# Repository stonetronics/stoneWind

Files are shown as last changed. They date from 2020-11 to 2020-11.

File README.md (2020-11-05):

# stoneWind

anemometer firmware for arduino uno based anemometer

This firmware and hardware enables an Arduino Uno to read the anemometer sensor found on https://www.thingiverse.com/thing:4216504
The Arduino shield (/hw) is drawn in Eagle 9.2.2, the Gerbers were generated for JLCPCB manufacturing
The Firmware (/src) is programmed in platformio

Features:
- 7 segment display
- sd card for logging and storage of lookup table
- ptc temperature sensor
- frequency counter
- schmitt trigger and signal conditioning/supply of the anemometer

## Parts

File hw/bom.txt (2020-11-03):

Stückliste exportiert aus /home/stone/GIT/stoneWind/hw/arduinoShield.sch am 18.09.20 22:02

Qty Value            Device                     Package          Parts                                           Description                                                                              CREATED_BY    DIGIKEY_PART_NUMBER MANUFACTURER     MF MPN      OC_FARNELL OC_NEWARK PACKAGE        PROD_ID     SPICEMODEL SPICEPREFIX SPICEPREFIXL VALUE         
1                    10-XX                      B3F-10XX         S1                                              OMRON SWITCH                                                                                                                                   B3F-1000 176432     36M3542                                                                                
3                    PINHD-1X1                  1X01             JP3, JP4, JP5                                   PIN HEADER                                                                                                                                                                                                                                                
1                    PINHD-1X2                  1X02             JP6                                             PIN HEADER                                                                                                                                                                                                                                                
2                    PINHD-1X4                  1X04             JP1, JP2                                        PIN HEADER                                                                                                                                                                                                                                                
3   100k             R-EU_R0805                 R0805            R7, R8, R14                                     RESISTOR, European symbol                                                                                                                                                                                          R                                      
10  100n             C-EUC0805                  C0805            C1, C2, C3, C7, C8, C9, C11, C12, C16, C18      CAPACITOR, European symbol                                                                                                                                                                                         C                                      
5   10k              R-EU_R0805                 R0805            R3, R4, R9, R13, R16                            RESISTOR, European symbol                                                                                                                                                                                          R                                      
6   150u             CPOL-EUD/7343-31R          D/7343-31R       C6, C10, C13, C14, C15, C17                     POLARIZED CAPACITOR, European symbol                                                                                                                                                                               C                                      
10  180R             R-EU_R0805                 R0805            R1, R15, R19, R20, R21, R22, R23, R24, R25, R26 RESISTOR, European symbol                                                                                                                                                                                          R                                      
1   1k5/1k8          R-EU_R0805                 R0805            R2                                              RESISTOR, European symbol                                                                                                                                                                                          R                                      
2   220k             R-EU_R0805                 R0805            R5, R6                                          RESISTOR, European symbol                                                                                                                                                                                          R                                      
1   2V4              DIODE-ZENER-BZT52C3V6S     SOD-323          D1                                              Zener Diode                                                                                                                                                                                 DIO-08199                                       3.6V          
1   330R             R-EU_R0805                 R0805            R12                                             RESISTOR, European symbol                                                                                                                                                                                          R                                      
2   4.3A/20V/54mΩ    MOSFET_PCH-IRLML2244       SOT23-3          Q3, Q4                                          P-channel MOSFETs                                                                                                                                                                           TRANS-11153                                     4.3A/20V/54mΩ 
2   500k             R-TRIMM64Y                 RTRIM64Y         R10, R11                                        Trimm resistor                                                                                                                                                                                          X                      POT                        
1   ARDUINO_UNO_R3   ARDUINO_UNO_R3_HOLES_NOISP ARDUINO_R3_NOISP B2                                                                                                                                                                                                                                                                                                        
1   BC847            BC847-NPN-SOT23-BEC        SOT23-BEC        T2                                              NPN Transistror                                                                                                                                                                                                                                           
1   BSS138           MOSFET-NCH-BSS138          SOT23-3          Q1                                              N-channel MOSFETs                                                                                                                                                                           TRANS-00830                                     220mA/50V/3.5Ω
1   IRLML2244        MOSFET_PCH-IRLML2244       SOT23-3          Q2                                              P-channel MOSFETs                                                                                                                                                                           TRANS-11153                                     4.3A/20V/54mΩ 
1   LM358D           LM358D                     SO08             IC1                                             OP AMP also LM158; LM258; LM2904                                                                                                                                                                                                                          
4   PESD5V0X1UB      PESD5V0X1UB                SOD523           D2, D3, D4, D5                                  Ultra low capacitance unidirectional ElectroStatic Discharge (ESD) protection diode in a                                                                                                                                                                  
1   PHOTOINTERRUPTER MKDSN1,5/3-5,08            MKDSN1,5/3-5,08  X2                                              MKDSN 1,5/ 3-5,08 Printklemme                                                                                                                                                                                                                             
1   PT100            PCB2_TERMINAL-BLOCK        2_2.54MM         X1                                              2 way PCB terminal block 2.54mm                                                                                                                                                                                                                           
1   REDSEVENSEGMENT  REDSEVENSEGMENT            REDSEVENSEGMENT  SSEG1                                           red 3 digit seven segment from neuhold electronic                                                                                                                                                                                                         
1   SDCARD_MODULE    SDCARD_MODULE              SD_MODULE        SD1                                             sd card module                                                                                                                                                                                                                                            
1   SS12             SS12                       SMA              D6                                              DIODE SCHOTTKY 20V 1A SMA                                                                PCBLayout.com SS12FSCT-ND         ON Semiconductor    SS12                          SMA (DO-214AC)                                                               
1   SUPPLY           MKDSN1,5/2-5,08            MKDSN1,5/2-5,08  X3                                              MKDSN 1,5/ 2-5,08 Printklemme

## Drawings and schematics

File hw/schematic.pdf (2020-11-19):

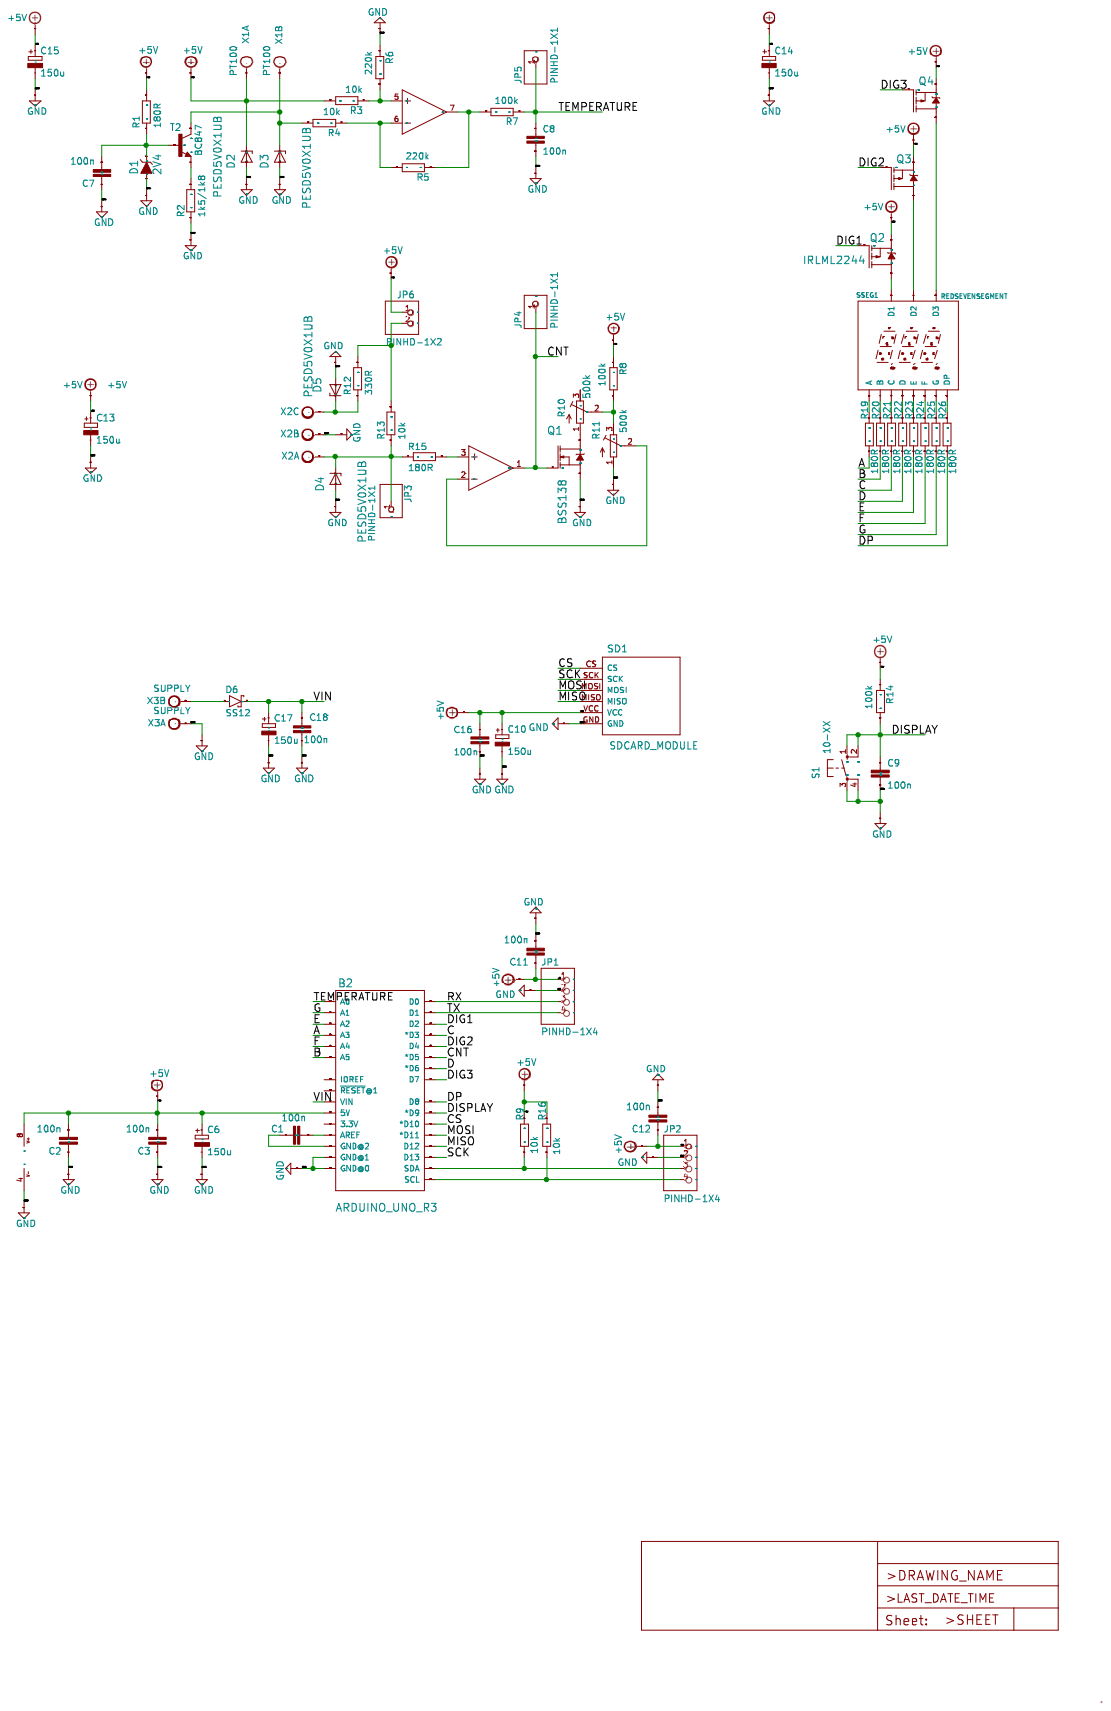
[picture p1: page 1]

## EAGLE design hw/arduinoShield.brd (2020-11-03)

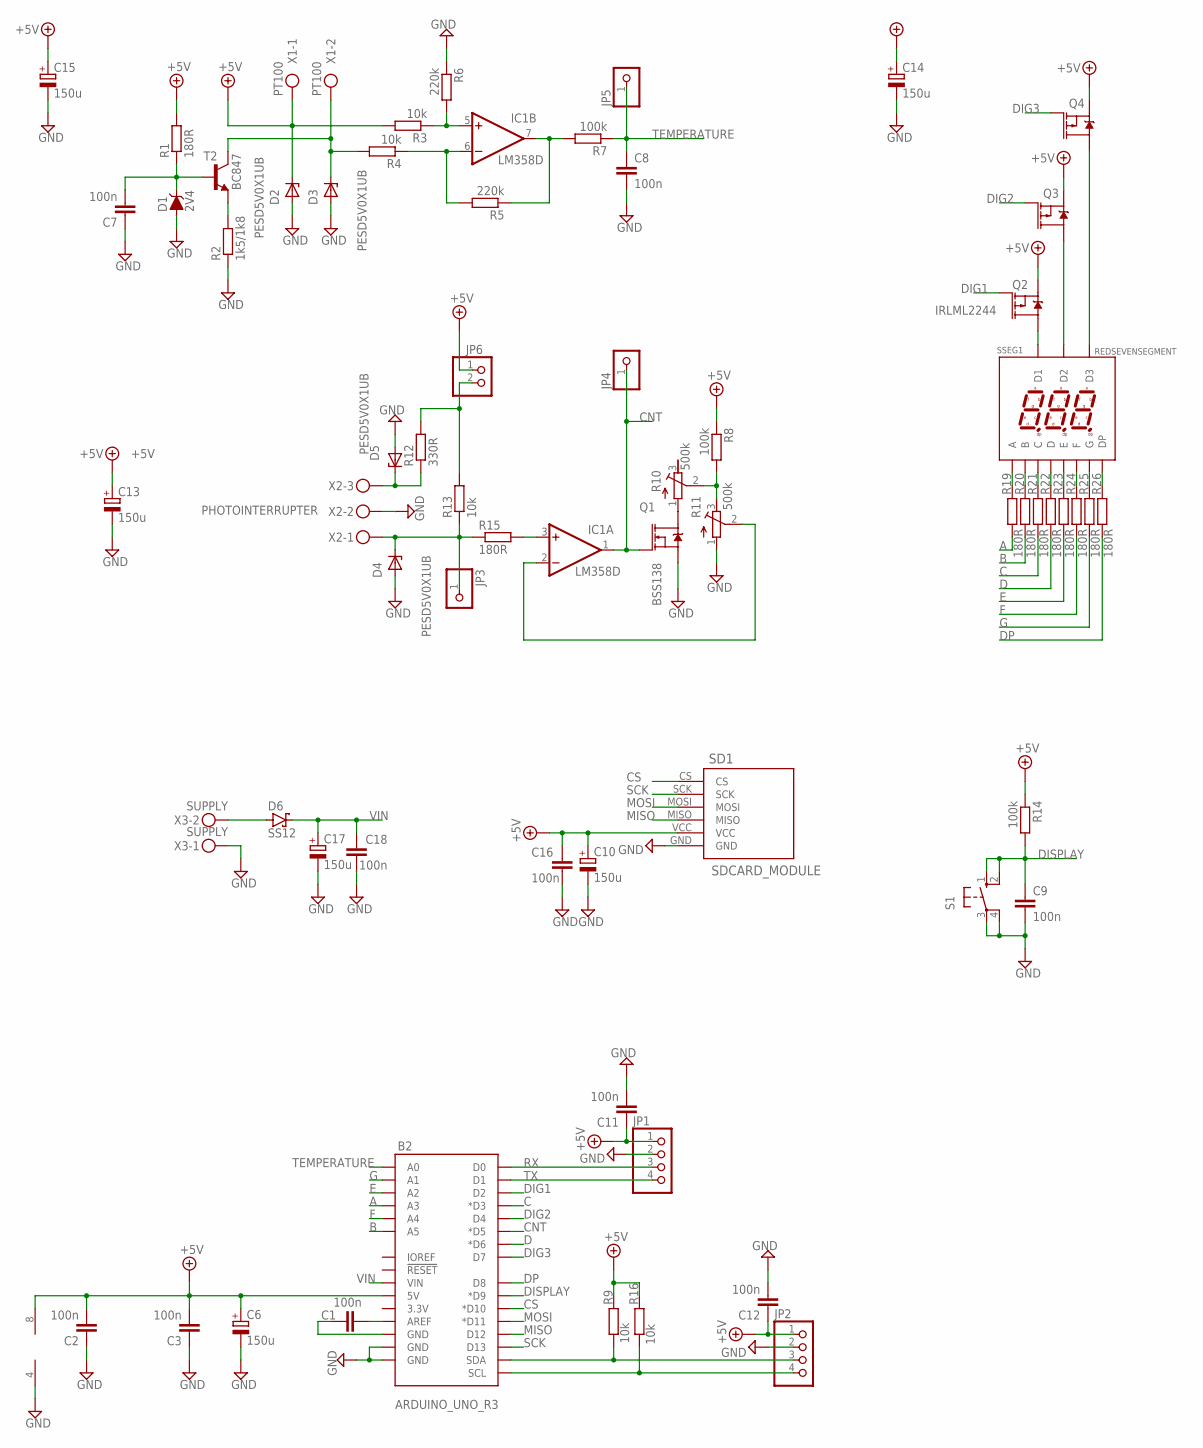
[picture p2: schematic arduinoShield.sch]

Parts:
B2: ARDUINO_UNO_R3; ARDUINO_R3_NOISP
C1, C2, C3, C7, C8, C9, C11, C12, C16, C18: 100n; C0805
C6, C10, C13, C14, C15, C17: 150u; D/7343-31R
D1: 2V4; SOD-323
D2, D3, D4, D5: PESD5V0X1UB; SOD523
D6: SS12; SMA
IC1: LM358D; SO08
JP1, JP2: PINHD-1X4; 1X04
JP3, JP4, JP5: PINHD-1X1; 1X01
JP6: PINHD-1X2; 1X02
Q1: BSS138; SOT23-3
Q2: IRLML2244; SOT23-3
Q3, Q4: 4.3A/20V/54mΩ; SOT23-3
R1, R15, R19, R20, R21, R22, R23, R24, R25, R26: 180R; R0805
R2: 1k5/1k8; R0805
R3, R4, R9, R13, R16: 10k; R0805
R5, R6: 220k; R0805
R7, R8, R14: 100k; R0805
R10, R11: 500k; RTRIM64Y
R12: 330R; R0805
S1: 10-XX; B3F-10XX
SD1: SDCARD_MODULE; SD_MODULE
SSEG1: REDSEVENSEGMENT
T2: BC847; SOT23-BEC
X1: PT100; 2_2.54MM
X2: PHOTOINTERRUPTER; MKDSN1,5/3-5,08
X3: SUPPLY; MKDSN1,5/2-5,08

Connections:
+5V: B2.5V, C2.2, C3.2, C6.+, C10.+, C11.1, C12.1, C13.+, C14.+, C15.+, C16.1, D2.1 (K), IC1.8 (V+), JP1.1, JP2.1, JP6.1, Q2.2 (S), Q3.2 (S), Q4.2 (S), R1.2, R3.2, R8.1, R9.2, R14.1, R16.2, SD1.VCC, X1.1
A: B2.A3, R19.1
B: B2.A5, R20.1
C: B2.D3 (*D3), R21.1
CNT: B2.D5 (*D5), IC1.1 (OUT), JP4.1, Q1.1 (G)
CS: B2.D10 (*D10), SD1.CS
D: B2.D6 (*D6), R22.1
DIG1: B2.D2, Q2.1 (G)
DIG2: B2.D4, Q3.1 (G)
DIG3: B2.D7, Q4.1 (G)
DISPLAY: B2.D9 (*D9), C9.1, R14.2, S1.1 (S), S1.2 (S1)
DP: B2.D8, R26.1
E: B2.A2, R23.1
F: B2.A4, R24.1
G: B2.A1, R25.1
GND: B2.GND@1 (GND), B2.GND@2 (GND), C2.1, C3.1, C6.-, C7.1, C8.2, C9.2, C10.-, C11.2, C12.2, C13.-, C14.-, C15.-, C16.2, C17.-, C18.1, D1.A, D2.2 (A), D3.2 (A), D4.2 (A), D5.2 (A), IC1.4 (V-), JP1.2, JP2.2, Q1.2 (S), R2.1, R6.1, R11.1 (A), S1.3, S1.4 (P1), SD1.GND, X2.2, X3.1
MISO: B2.D12, SD1.MISO
MOSI: B2.D11 (*D11), SD1.MOSI
unnamed: B2.AREF, C1.2
unnamed: C7.2, D1.C, R1.1, T2.B
unnamed: R2.2, T2.E
unnamed: D3.1 (K), R4.2, T2.C, X1.2
unnamed: IC1.5 (+IN), R3.1, R6.2
unnamed: IC1.6 (-IN), R4.1, R5.2
unnamed: IC1.7 (OUT), R5.1, R7.2
unnamed: D5.1 (K), R12.1, X2.3
unnamed: B2.SDA, JP2.3, R9.1
unnamed: Q1.3 (D), R10.1 (A)
unnamed: R8.2, R10.2 (S), R11.3 (E)
unnamed: IC1.2 (-IN), R11.2 (S)
unnamed: D4.1 (K), JP3.1, R13.1, R15.1, X2.1
unnamed: B2.SCL, JP2.4, R16.1
unnamed: JP6.2, R12.2, R13.2
unnamed: B2.GND@3 (GND), C1.1
unnamed: Q2.3 (D), SSEG1.2 (D1)
unnamed: Q3.3 (D), SSEG1.4 (D2)
unnamed: Q4.3 (D), SSEG1.5 (D3)
unnamed: D6.A, X3.2
unnamed: R19.2, SSEG1.9 (A)
unnamed: R20.2, SSEG1.7 (B)
unnamed: R21.2, SSEG1.1 (C)
unnamed: R22.2, SSEG1.3 (D)
unnamed: R23.2, SSEG1.10 (E)
unnamed: R24.2, SSEG1.8 (F)
unnamed: R25.2, SSEG1.11 (G)
unnamed: R26.2, SSEG1.6 (DP)
unnamed: IC1.3 (+IN), R15.2
RX: B2.D0, JP1.3
SCK: B2.D13, SD1.SCK
TEMPERATURE: B2.A0, C8.1, JP5.1, R7.1
TX: B2.D1, JP1.4
VIN: B2.VIN, C17.+, C18.2, D6.C

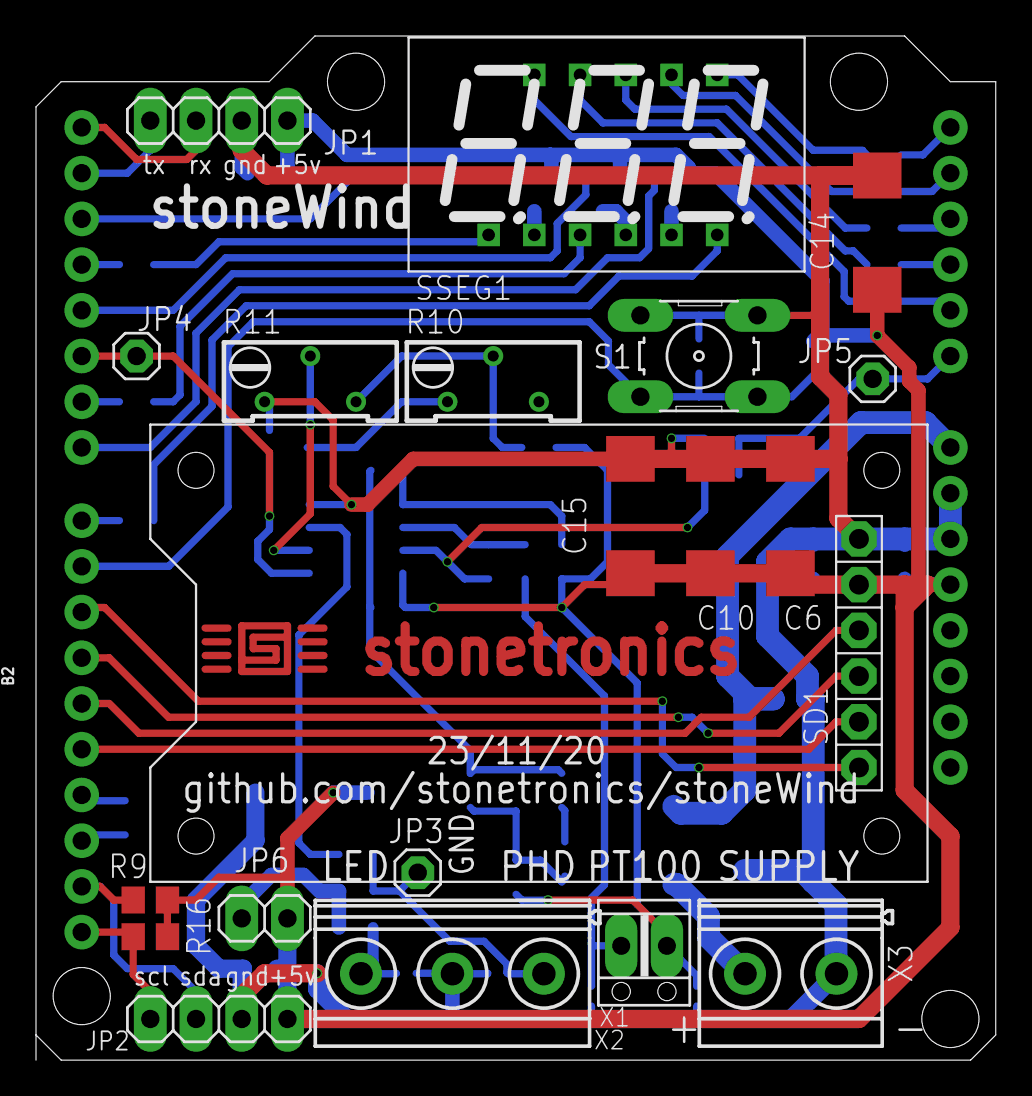
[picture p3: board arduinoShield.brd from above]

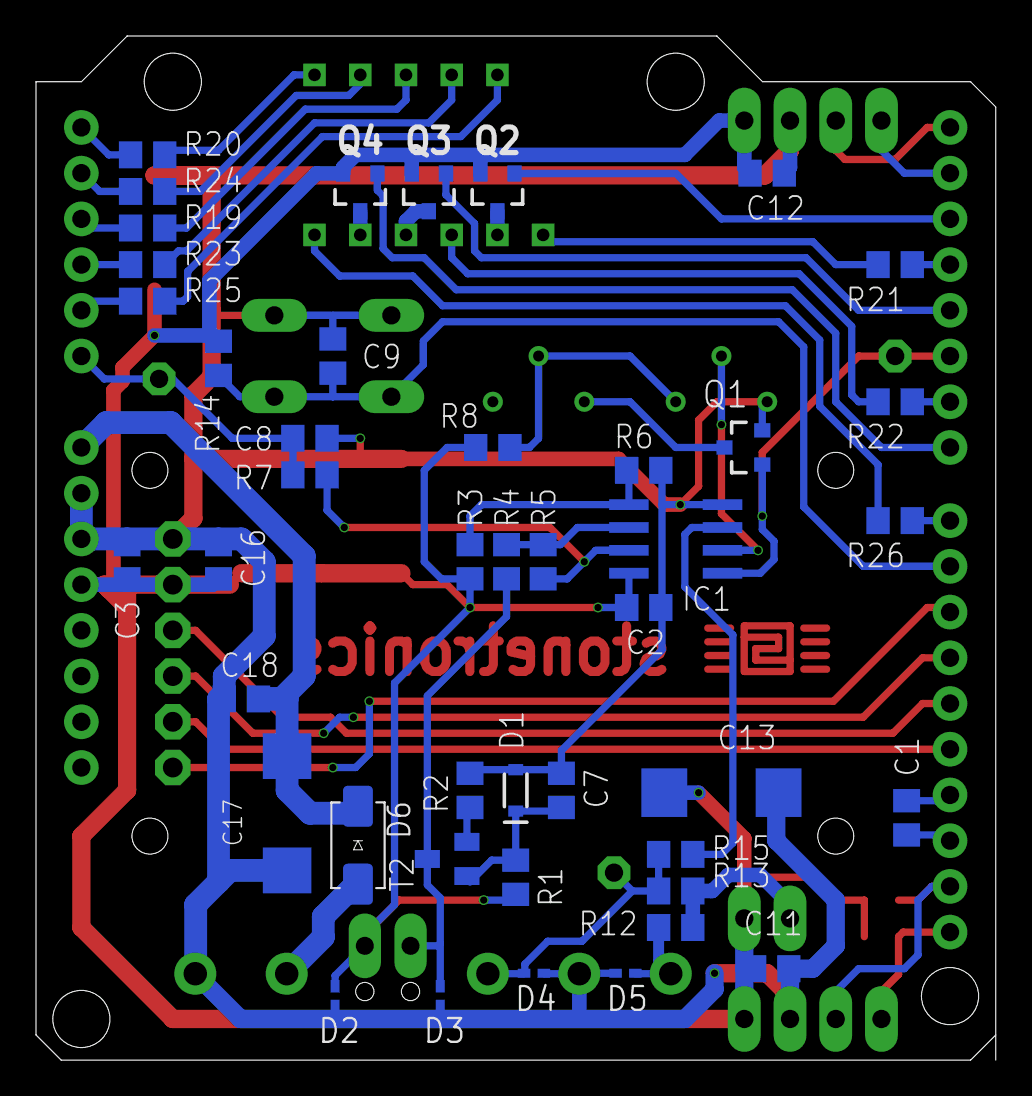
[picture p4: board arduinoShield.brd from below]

Board: 2 copper layers, 53.3 x 56.9 mm, 65 parts (44 on the bottom side), 52 nets.

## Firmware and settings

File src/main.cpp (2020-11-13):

#include <Arduino.h>
#include <SPI.h>
#include <SD.h>

#include "pindef.h"
#include "sevenSegment.h"
#include "freqCount.h"
#include "lookupTable.h"

LookupTable windFreqLUT;
LookupTable tempAdcLUT;

void setup() {
  Serial.begin(9600); //init serial
  Serial.println("stoneWind Anemomenter");

  //sd card init

  Serial.println("initializing SD card");
  if (!SD.begin(PIN_CS)) {
    Serial.println("initialization failed!");
    Serial.println("please insert sd card an reset");
    while (1);
  }
  Serial.println("initialization done.");

  //load lookup tables

  Serial.println("loading wind/frequency lookup table from /LUT/windFreq.csv");
  windFreqLUT.begin(12);
  if (windFreqLUT.loadFromFile("LUT/windFreq.csv") )
  {
    Serial.println("loading successful!");
    Serial.println("lookup table values:");
    windFreqLUT.printTable();
  } else {
    Serial.println("couldn't load wind/freq LUT!");
    while(1);
  }

  Serial.println("loading temperature/ADC lookup table from /LUT/tempAdc.csv");
  tempAdcLUT.begin(12);
  if (tempAdcLUT.loadFromFile("LUT/tempAdc.csv") )
  {
    Serial.println("loading successful!");
    Serial.println("lookup table values:");
    tempAdcLUT.printTable();
  } else {
    Serial.println("couldn't load temp/adc LUT!");
    while(1);
  }

  //initialize pushbutton

  pinMode(PIN_DISPLAY, INPUT);

  //initialize 7 segment and freq counter

  sevenSegmentInit(); //setup portpins, timer, etc
  sevenSegmentEnable();
  freqCountInit();
  freqCountSetTimebase(2000);
  sei(); //enable interrupts
}

void loop() {
  static uint32_t millisBefore = 0;
  static uint32_t millisBtnPush = 0;
  static uint8_t displayMode = 0; //0 = no display, 1 = wind, 2 = temperature
  //read time and measure frequency and temperature adc
  uint32_t millisNow = freqCountGetTotalMillis();
  float measuredFrequency = freqCountGetFreq();
  uint16_t measuredADC = analogRead(PIN_TEMPERATURE);

  //calculate the wind
  float calculatedWind = windFreqLUT.getYfromX(measuredFrequency);
  float calculatedTemp = tempAdcLUT.getYfromX(measuredADC);

  //read button for display mode
  static uint8_t btnOld = 0;
  uint8_t btn = digitalRead(PIN_DISPLAY);

  if (btnOld != btn)
  {
    btnOld = btn;
    if (!btn) //button onPush action
    {
      millisBtnPush = millisNow;
      //switch through display modes
      displayMode++;
      if (displayMode == 3)
        displayMode = 0;
    }
  }

  //display the measured value depending on the display mode
  switch (displayMode)
  {
      case 0:
        sevenSegmentClear();
        break;
      case 1:
        //display the measured wind speed
        sevenSegmentDisplayNumberWithDp(calculatedWind);
        break;
      case 2:
        //display the measured temperature
        sevenSegmentDisplayNumberWithDp(calculatedTemp);
        break;
      default:
        break;
  }

  if (millisNow - millisBtnPush > 35000)  //reset the display after a while
  {
    //reset display mode
    displayMode = 0;
  }

  if (millisNow - millisBefore > 5000) //every 5s
  {
    //print
    Serial.print(millisNow);
    Serial.print(": ");
    Serial.print("Wind: ");
    Serial.print(calculatedWind);
    Serial.print(" km/h | Temperature: ");
    Serial.print(calculatedTemp);
    Serial.println(" deg C");

    //open csv and write to it
    File logFile = SD.open("log.csv", FILE_WRITE);
    if (logFile)
    {
      logFile.print(millisNow);
      logFile.print(",");
      logFile.print(calculatedWind);
      logFile.print(",");
      logFile.println(calculatedTemp);
      logFile.close();
    }
    else
    {
      Serial.println("Couldn't open log file 'log.csv'");
    }


    //save the time now for the next iteration
    millisBefore = millisNow;
  }

}

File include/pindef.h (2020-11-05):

#ifndef __pindef_h__
#define __pindef_h__

#define PIN_TEMPERATURE   14
#define PIN_G             15
#define PIN_E             16
#define PIN_A             17
#define PIN_F             18
#define PIN_B             19
#define PIN_RX            0
#define PIN_TX            1
#define PIN_DIG1          2
#define PIN_C             3
#define PIN_DIG2          4
#define PIN_CNT           5
#define PIN_D             6
#define PIN_DIG3          7
#define PIN_DP            8
#define PIN_DISPLAY       9
#define PIN_CS            10
#define PIN_MOSI          11
#define PIN_MISO          12
#define PIN_SCK           13

#endif

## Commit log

2020-11-03 First PCB design
    [arduinoShield.brd, arduinoShield.sch]
2020-11-05 add seven segment driver and frequency counting for measuring wind speed
2020-11-05 add Lookup Table and millis() handling, update readme
2020-11-13 transform LUT from static to class, LUT loading from sd card file csv data log to sd card
    [arduinoShield.brd, arduinoShield.sch]
2020-11-19 add pdf schematic

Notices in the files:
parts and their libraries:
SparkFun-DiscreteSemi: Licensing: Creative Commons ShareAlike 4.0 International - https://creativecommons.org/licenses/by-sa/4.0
